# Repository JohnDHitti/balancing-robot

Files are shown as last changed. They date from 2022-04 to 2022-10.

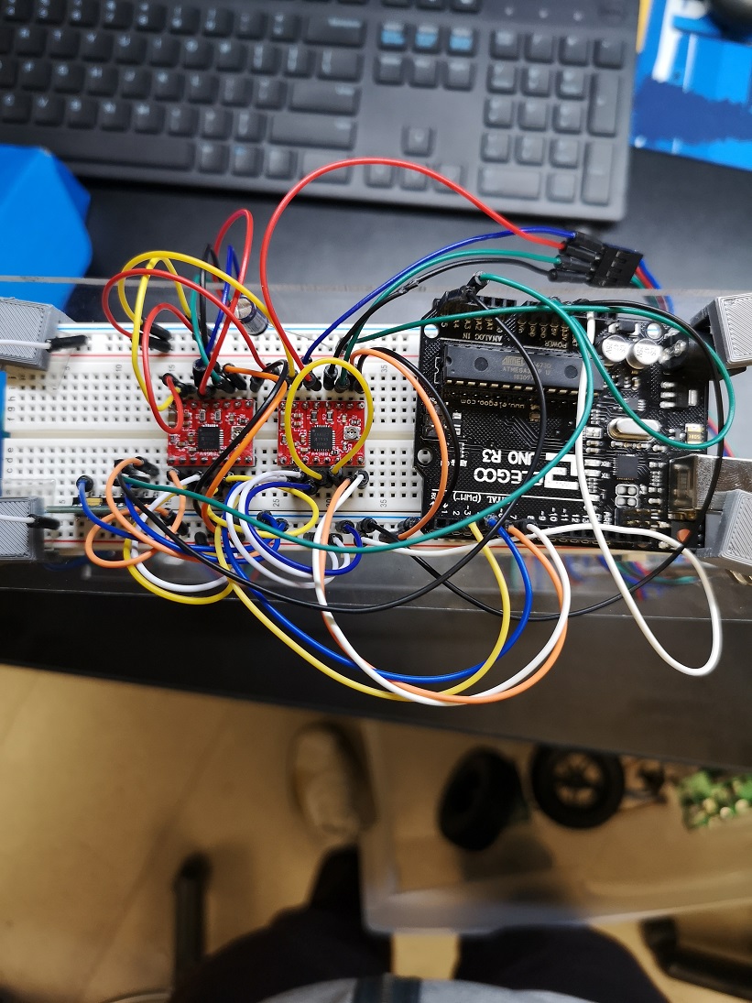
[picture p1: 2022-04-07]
images/IMG_20211213_162925.jpg

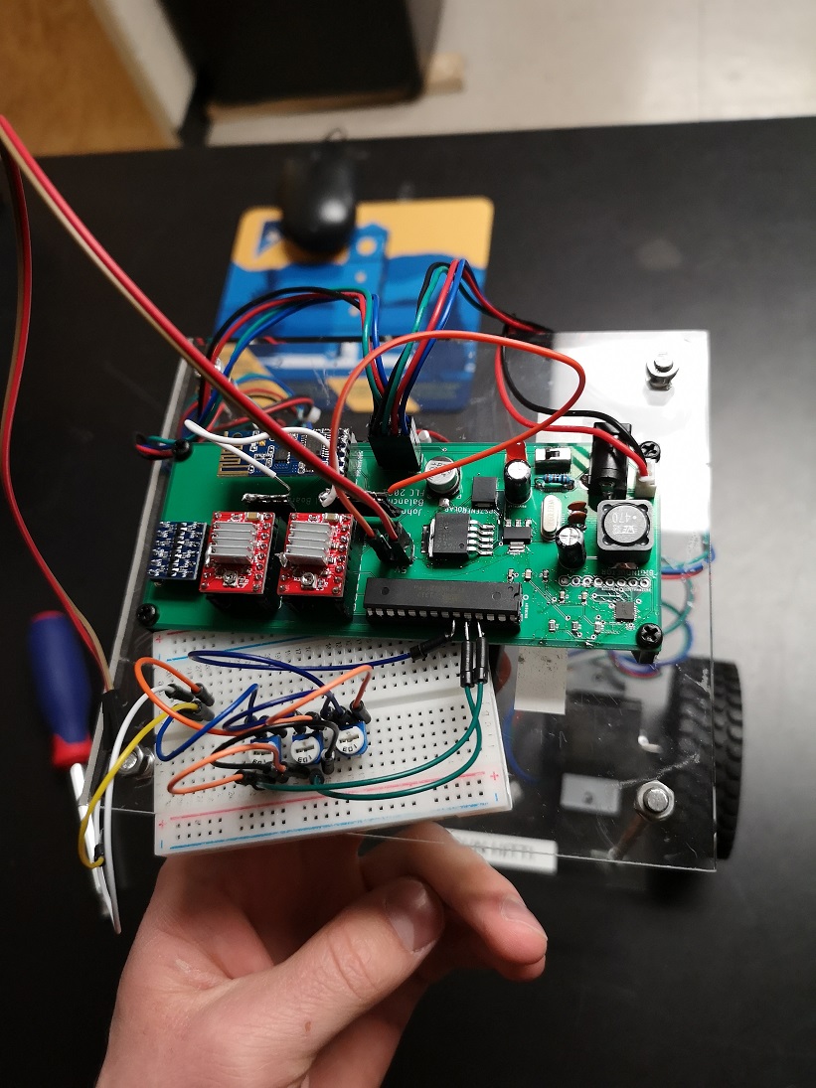
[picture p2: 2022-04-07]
images/IMG_20211210_155559.jpg

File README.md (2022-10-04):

# balancing-robot
Source code for a balancing robot project conducted at Fort Lewis College. The balancing robot was a project where an atmega328p was used as a PID controller on a custom PCB to control two stepper motors to balance a vertical tower shaped robot. This robot also featured a wireless remote control option. (Pre-freeRTOS)

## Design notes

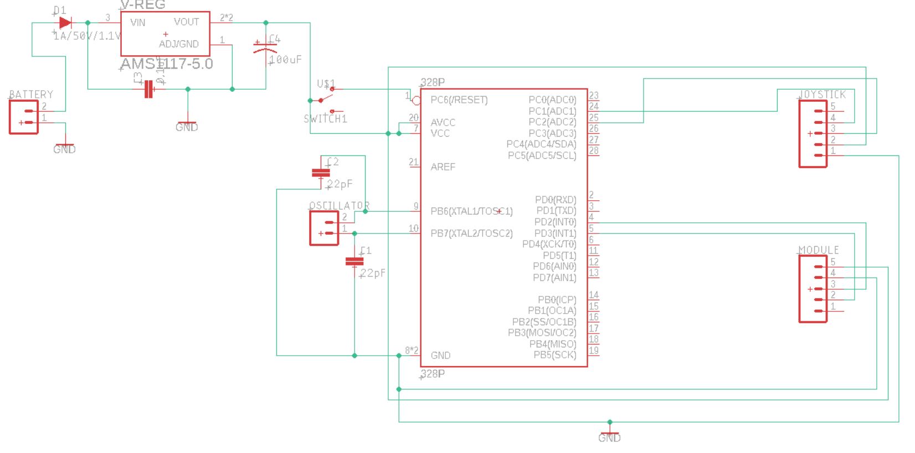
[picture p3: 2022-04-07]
images/js schematic.JPG

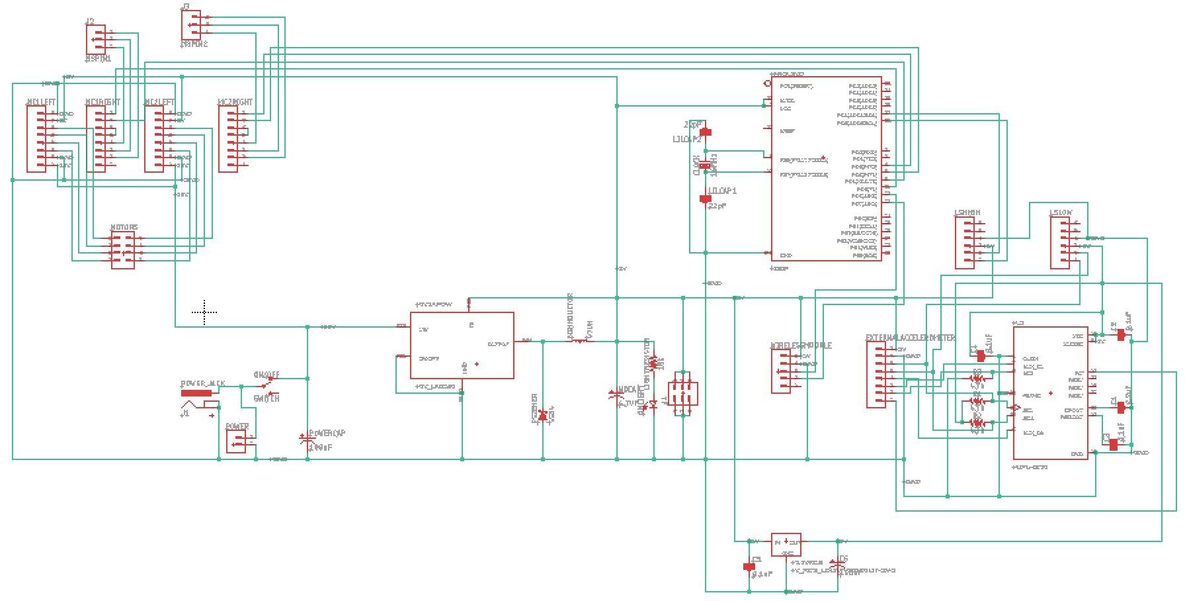
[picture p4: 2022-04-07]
images/schematic.JPG

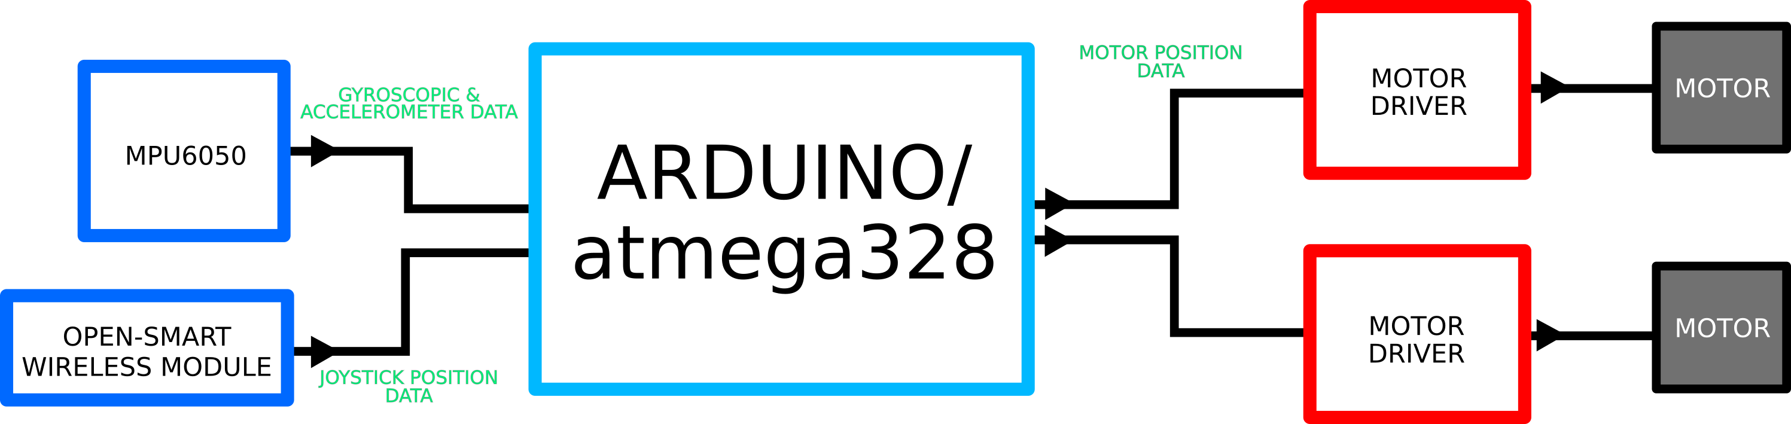
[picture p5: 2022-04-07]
images/flowRoot1304.png

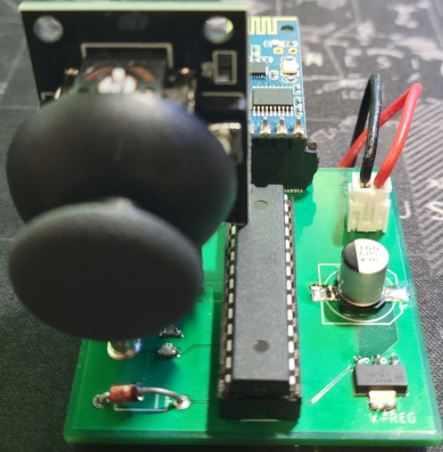
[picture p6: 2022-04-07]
images/js.JPG

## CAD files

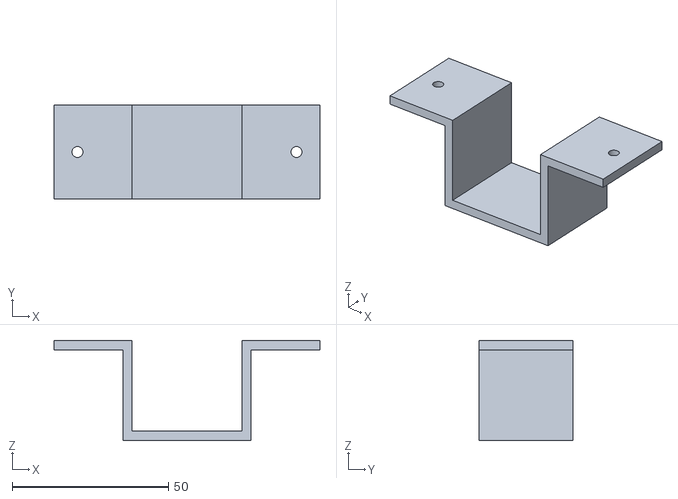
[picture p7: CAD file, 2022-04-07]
3D_printed_files_for_robot/BatteryClamp.STL
85.0 x 30.0 x 32.0

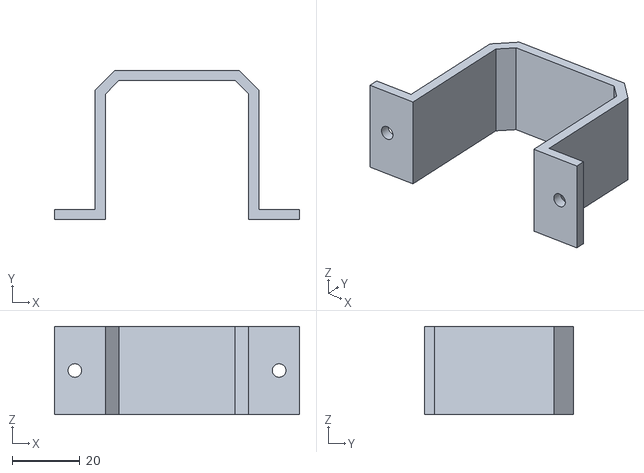
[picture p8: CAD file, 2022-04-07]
3D_printed_files_for_robot/UBracket.STL
72.2 x 44.0 x 26.0

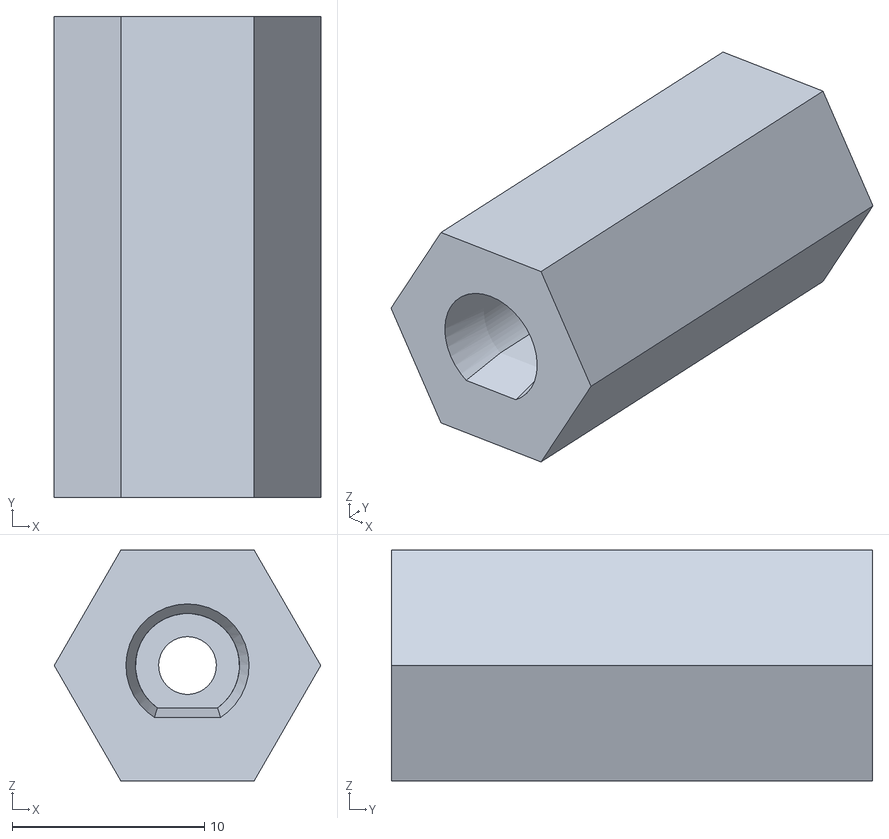
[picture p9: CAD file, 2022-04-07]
3D_printed_files_for_robot/Wheel-Adapter.STL
13.9 x 25.0 x 12.0

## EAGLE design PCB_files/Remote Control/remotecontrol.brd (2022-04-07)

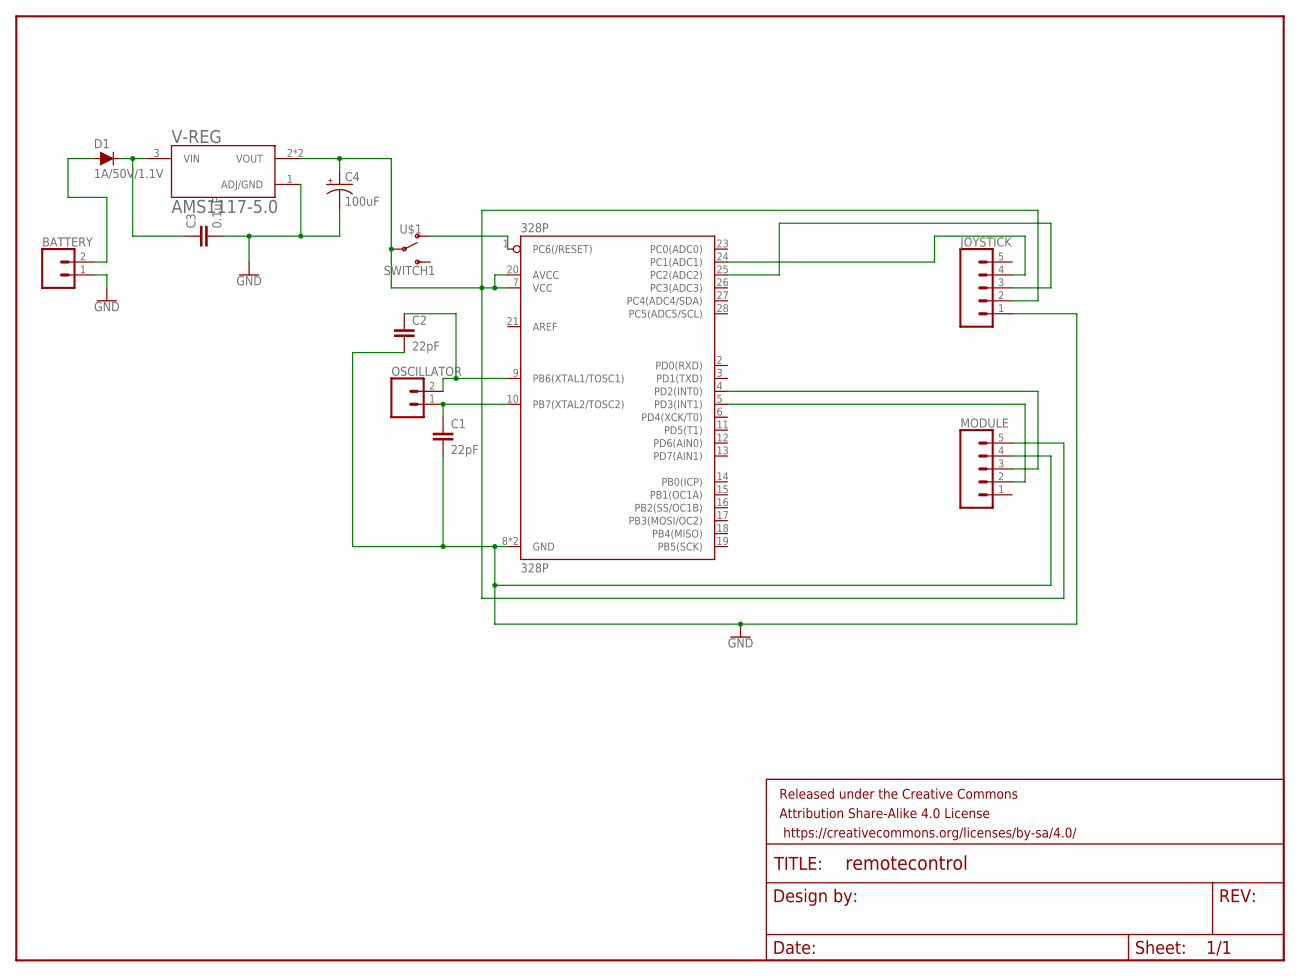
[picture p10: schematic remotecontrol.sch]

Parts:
328P: 328P; DIP28
BATTERY: CONN_02; 1X02
C1, C2: 22pF; 0603
C3: 0.1uF; 0603
C4: 100uF; NIC_10X10.5_CAP
D1: 1A/50V/1.1V; DIODE-1N4001
FRAME1: FRAME-LETTER; CREATIVE_COMMONS
JOYSTICK: CONN_05; 1X05
MODULE: CONN_05; 1X05
OSCILLATOR: CONN_02; 1X02
U$1: SWITCH1
V-REG: AMS1117-5.0; SOT229P700X180-4N

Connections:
GND: 328P.8 (GND), 328P.22 (GND), BATTERY.1, C1.2, C2.2, C3.2, C4.-, JOYSTICK.1, MODULE.4, V-REG.1 (ADJ/GND)
JOYSTICK: 328P.24 (PC1(ADC1)), JOYSTICK.4
unnamed: 328P.5 (PD3(INT1)), MODULE.2
unnamed: 328P.4 (PD2(INT0)), MODULE.3
unnamed: BATTERY.2, D1.A
unnamed: 328P.25 (PC2(ADC2)), JOYSTICK.3
unnamed: C3.1, D1.C, V-REG.3 (VIN)
unnamed: 328P.10 (PB7(XTAL2/TOSC2)), C1.1, OSCILLATOR.1
unnamed: 328P.9 (PB6(XTAL1/TOSC1)), C2.1, OSCILLATOR.2
unnamed: 328P.1 (PC6(/RESET)), U$1.P$3 (O)
unnamed: 328P.7 (VCC), 328P.20 (AVCC), C4.+, JOYSTICK.2, MODULE.5, U$1.P$2, V-REG.2 (VOUT), V-REG.4 (VOUT)

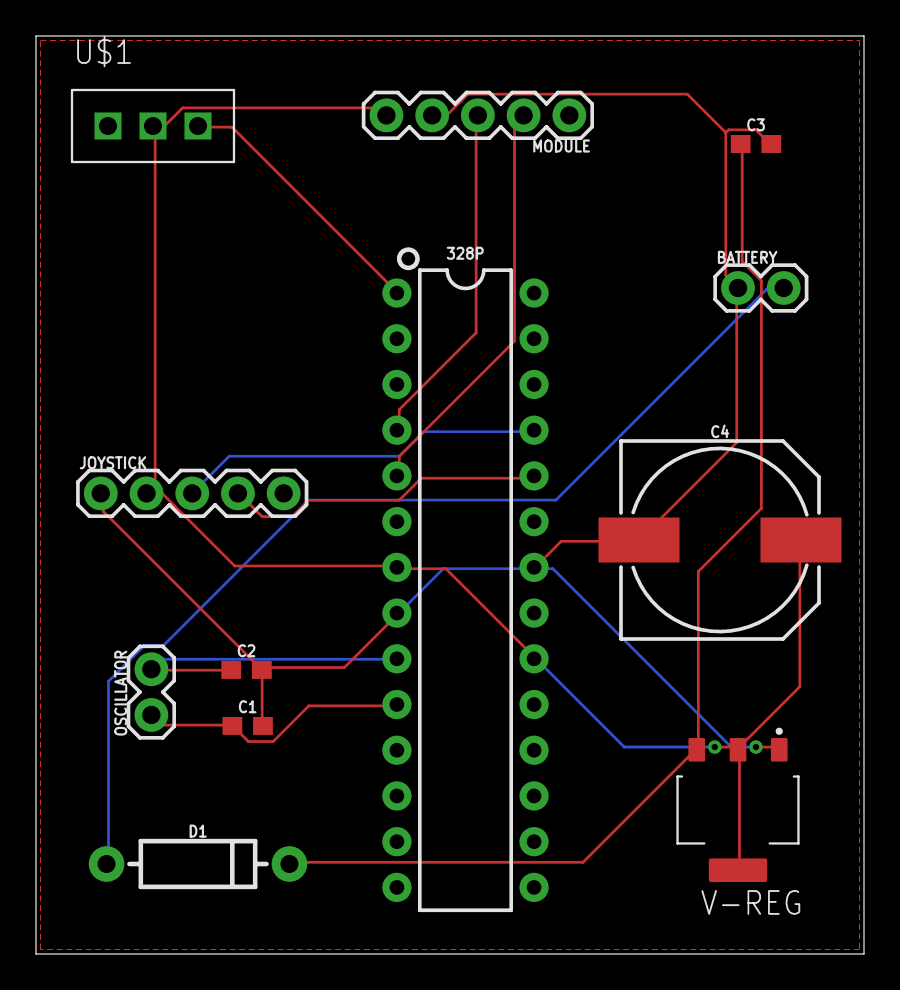
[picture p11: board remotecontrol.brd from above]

Board: 2 copper layers, 46.0 x 51.0 mm, 13 parts (0 on the bottom side), 11 nets.

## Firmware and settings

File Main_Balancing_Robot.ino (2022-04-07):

// JOHN HITTI

#include <Wire.h>                                            //Include the Wire.h library so we can communicate with the gyro
int MPU = 0x68;                                              //MPU-6050 I2C address (0x68 or 0x69)
int acc_calibration_value = -8160;                            //Enter the accelerometer calibration value (IMPORTANT to find yours)
float pid_p_gain = 100;                                       //Gain setting for the P-controller (15)
float pid_i_gain = 15;                                      //Gain setting for the I-controller (1.5)
float pid_d_gain = 145;                                       //Gain setting for the D-controller (30)
long delayToBeAdded, counter_motor, gyro_pitch_calibration_value;
int receive_counter, gyro_pitch_data_raw, accelerometer_data_raw;
unsigned long loop_timer;
float angle_gyro, angle_acc, pid_error_temp, pid_i_mem, pid_output, pid_last_d_error;

void setup() {
  Serial.begin(9600);
  Wire.begin();                                                             //Start the I2C bus as master
  TWBR = 12;                                                                //Set the I2C clock speed to 400kHz
  //To create a variable pulse for controlling the stepper motors a timer is created that will execute a piece of code (subroutine) every 20us
  //This subroutine is called TIMER2_COMPA_vect
  TCCR2A = 0;                                                               //Make sure that the TCCR2A register is set to zero
  TCCR2B = 0;                                                               //Make sure that the TCCR2A register is set to zero
  TIMSK2 |= (1 << OCIE2A);                                                  //Set the interupt enable bit OCIE2A in the TIMSK2 register
  TCCR2B |= (1 << CS21);                                                    //Set the CS21 bit in the TCCRB register to set the prescaler to 8
  OCR2A = 39;                                                               //The compare register is set to 39 => 20us / (1s / (16.000.000MHz / 8)) - 1
  TCCR2A |= (1 << WGM21);                                                   //Set counter 2 to CTC (clear timer on compare) mode

  //By default the MPU-6050 sleeps. So we have to wake it up.
  Wire.beginTransmission(MPU);                                              //Start communication with the address found during search.
  Wire.write(0x6B);                                                         //We want to write to the PWR_MGMT_1 register (6B hex)
  Wire.write(0x00);                                                         //Set the register bits as 00000000 to activate the gyro
  Wire.endTransmission();                                                   //End the transmission with the gyro.
  //Set the full scale of the gyro to +/- 250 degrees per second
  Wire.beginTransmission(MPU);                                              //Start communication with the address found during search.
  Wire.write(0x1B);                                                         //We want to write to the GYRO_CONFIG register (1B hex)
  Wire.write(0x00);                                                         //Set the register bits as 00000000 (250dps full scale)
  Wire.endTransmission();                                                   //End the transmission with the gyro
  //Set the full scale of the accelerometer to +/- 4g.
  Wire.beginTransmission(MPU);                                              //Start communication with the address found during search.
  Wire.write(0x1C);                                                         //We want to write to the ACCEL_CONFIG register (1A hex)
  Wire.write(0x08);                                                         //Set the register bits as 00001000 (+/- 4g full scale range)
  Wire.endTransmission();                                                   //End the transmission with the gyro
  //Set some filtering to improve the raw data. CRITICAL!!
  Wire.beginTransmission(MPU);                                              //Start communication with the address found during search
  Wire.write(0x1A);                                                         //We want to write to the CONFIG register (1A hex)
  Wire.write(0x03);                                                         //Set the register bits as 00000011 (Set Digital Low Pass Filter to ~43Hz)
  Wire.endTransmission();                                                   //End the transmission with the gyro

  pinMode(2, OUTPUT);                                                       //Configure digital poort 2 as output
  pinMode(3, OUTPUT);                                                       //Configure digital poort 3 as output
  pinMode(4, OUTPUT);                                                       //Configure digital poort 4 as output
  pinMode(5, OUTPUT);                                                       //Configure digital poort 5 as output
  pinMode(13, OUTPUT);                                                      //Configure digital poort 13 as output

  for (receive_counter = 0; receive_counter < 500; receive_counter++) {     //Create 500 loops
    if (receive_counter % 15 == 0)digitalWrite(13, !digitalRead(13));       //Change the state of the LED every 15 loops to make the LED blink fast
    Wire.beginTransmission(MPU);                                            //Start communication with the gyro
    Wire.write(0x43);                                                       //Gyro Y_OUT
    Wire.endTransmission();                                                 //End the transmission
    Wire.requestFrom(MPU, 2);                                               //Request 2 bytes from the gyro
    gyro_pitch_calibration_value += Wire.read() << 8 | Wire.read();         //Combine the two bytes to make one integer
    delayMicroseconds(3700);                                                //Wait for 3700 microseconds to simulate the main program loop time, CRITICALL!!
  }
  gyro_pitch_calibration_value /= 500;                                      //Divide the total value by 500 to get the avarage gyro offset
  loop_timer = micros() + 4000;                                             //Set the loop_timer variable at the next end loop time
}

void loop() {

  pid_p_gain = map(analogRead(A0), 0, 1028, 0, 300);
 pid_i_gain = map(analogRead(A1), 0, 1028, 0, 50);
  pid_d_gain = map(analogRead(A2), 0, 1028, 0, 300);

  
  Wire.beginTransmission(MPU);                                              //Start communication with the gyro
  Wire.write(0x3F);                                                         //Start reading at register 3F
  Wire.endTransmission();                                                   //End the transmission
  Wire.requestFrom(MPU, 2);                                                 //Request 2 bytes from the gyro
  accelerometer_data_raw = Wire.read() << 8 | Wire.read();                  //Combine the two bytes to make one integer
  accelerometer_data_raw += acc_calibration_value;                          //Add the accelerometer calibration value

  if (accelerometer_data_raw > 8192)accelerometer_data_raw = 8192;          //Limiting the acc data to +/-8192;
  if (accelerometer_data_raw < -8192)accelerometer_data_raw = -8192;
  angle_acc = asin((float)accelerometer_data_raw / 8192.0) * 57.296;        //Calculate the current angle according to the accelerometer
  Wire.beginTransmission(MPU);                                              //Start communication with the gyro
  Wire.write(0x43);                                                         //Start reading at register 45
  Wire.endTransmission();                                                   //End the transmission
  Wire.requestFrom(MPU, 2);                                                 //Request 2 bytes from the gyro
  gyro_pitch_data_raw = Wire.read() << 8 | Wire.read();                     //Combine the two bytes to make one integer
  gyro_pitch_data_raw -= gyro_pitch_calibration_value;                      //Add the gyro calibration value
  angle_gyro += gyro_pitch_data_raw * 0.000031;                             //Calculate the traveled during this loop angle and add this to the angle_gyro variable
  angle_gyro = angle_gyro * 0.9996 + angle_acc * 0.0004;                    //Correct the drift of the gyro angle with the accelerometer angle
  pid_error_temp = angle_gyro - 0;                                          //Find the error between the current angle and 0

  pid_i_mem += pid_i_gain * pid_error_temp;                                 //Calculate the I-controller value and add it to the pid_i_mem variable
  if (pid_i_mem > 100)pid_i_mem = 100;                                      //Limit the I-controller to the maximum controller output
  else if (pid_i_mem < -100)pid_i_mem = -100;
  //Calculate the PID output value
  pid_output = pid_p_gain * pid_error_temp + pid_i_mem + pid_d_gain * (pid_error_temp - pid_last_d_error);
  if (pid_output > 100)pid_output = 100;                                    //Limit the PI-controller to the maximum controller output
  else if (pid_output < -100)pid_output = -100;
  pid_last_d_error = pid_error_temp;                                        //Store the error for the next loop
  if (pid_output < 5 && pid_output > -5)pid_output = 0;                     //Create a dead-band to stop the motors when the robot is balanced
  if (pid_output == 0) { // if the car is balanced, do not output any power to the motor
    delayToBeAdded = 0;
  }
  else
    delayToBeAdded = 5500 / (abs(pid_output) + 9);

  //The angle calculations are tuned for a loop time of 4 milliseconds. To make sure every loop is exactly 4 milliseconds a wait loop
  //is created by setting the loop_timer variable to +4000 microseconds every loop.
  Serial.print("angle_gyro: ");
  Serial.print(angle_gyro);
  Serial.print(" PID out: ");
  Serial.println(pid_output);
  //Serial.println();

  while (loop_timer > micros()); // while loop_timer > micros(), hold there and wait
  loop_timer += 4000;           // once loop_timer < micros(), add 4000 us to loop_timer.

}

ISR(TIMER2_COMPA_vect) {

  counter_motor ++;
  if (abs(delayToBeAdded) < 45) {
    return;
  }
  if (counter_motor > delayToBeAdded) {
    counter_motor = 0;
    if (pid_output > 0) {
      PORTD &= 0b00000000; //0b00DSDS00 (D: Dir, S: Step), make all zeros is for the next line to let the two wheels rototae in the different directions.
      PORTD |= 0b00000100; //Two different directions for the two steppers.
    }
    else {
      PORTD &= 0b00000000;
      PORTD |= 0b00100000; // Change the directions
    }
  }
  else if (counter_motor == 1)PORTD |= 0b00011000;            //Set output 2 high to create a pulse for the stepper controller
  else if (counter_motor == 2)PORTD &= 0b11100111;            //Set output 2 low because the pulse only has to last for 20us
}

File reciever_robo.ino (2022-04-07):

//// Example 1-1, joystick and open-smart wireless, TX
//#include <SoftwareSerial.h>
//const int joystickYPin = A1;
//int joystickMaxValue = 0;
// 
//SoftwareSerial BlueSerial(2, 3); // RX, TX
// 
//void setup() {
//  // set the data rate for the SoftwareSerial port
//  BlueSerial.begin(9600);
//}
// 
//void loop() {
//  int joystickValue = analogRead(joystickYPin);
//  BlueSerial.println(joystickValue);
//  delay(1000);
//}

// Example 1-2, joystick and open-smart wireless, RX
#include <SoftwareSerial.h>
 
SoftwareSerial BlueSerial(6, 7); // RX, TX
String incomingMessage="";;
void setup() {
  // Open serial communications and wait for port to open:
  Serial.begin(9600);
  // set the data rate for the SoftwareSerial port
  BlueSerial.begin(9600);
}
void loop() // run over and over
{
    while (BlueSerial.available())
    {
      Serial.print("avail");
        char character = BlueSerial.read(); // Receive a single character from the software serial port
        incomingMessage.concat(character); // Add the received character to the receive buffer
        if (character == '\n')// the message ends with '\n', so when '\n' shows up,
        // that data point is sent successfully.
        {
            Serial.print("Received: ");
            Serial.println(incomingMessage);
            Serial.println(incomingMessage.toInt());// convert string to int
            // Clear receive buffer so we're ready to receive the next line
            incomingMessage = "";
        }
    }

}

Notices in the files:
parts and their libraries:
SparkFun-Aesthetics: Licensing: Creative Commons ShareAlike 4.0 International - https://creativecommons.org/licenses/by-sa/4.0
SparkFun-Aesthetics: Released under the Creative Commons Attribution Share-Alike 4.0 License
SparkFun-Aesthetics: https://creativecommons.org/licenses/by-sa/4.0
